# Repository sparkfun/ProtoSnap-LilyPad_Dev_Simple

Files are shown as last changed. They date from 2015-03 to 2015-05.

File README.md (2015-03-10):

SparkFun ProtoSnap - LilyPad Development Simple
================================================

SparkFun ProtoSnap - LilyPad Development Simple

[*SparkFun ProtoSnap - LilyPad Development Simple (DEV-11201)*](https://www.sparkfun.com/products/11201)

The ProtoSnap LilyPad Simple Development board is a great way to get started in programmable e-textiles. 
By combining a LilyPad Simple board with 4 LED boards and a buzzer, the ProtoSnap LilyPad Simple Development board gives you everything you need to learn the basics. 

Repository Contents
-------------------

* **/Hardware** - All Eagle design files (.brd, .sch)

License Information
-------------------
The hardware is released under [Creative Commons ShareAlike 4.0 International](https://creativecommons.org/licenses/by-sa/4.0/).

Distributed as-is; no warranty is given.

_**Note:** A portion of this sale is given back to Dr. Leah Buechley for continued development and education of e-textiles and also to Arduino LLC to help fund continued development of new tools and new IDE features._

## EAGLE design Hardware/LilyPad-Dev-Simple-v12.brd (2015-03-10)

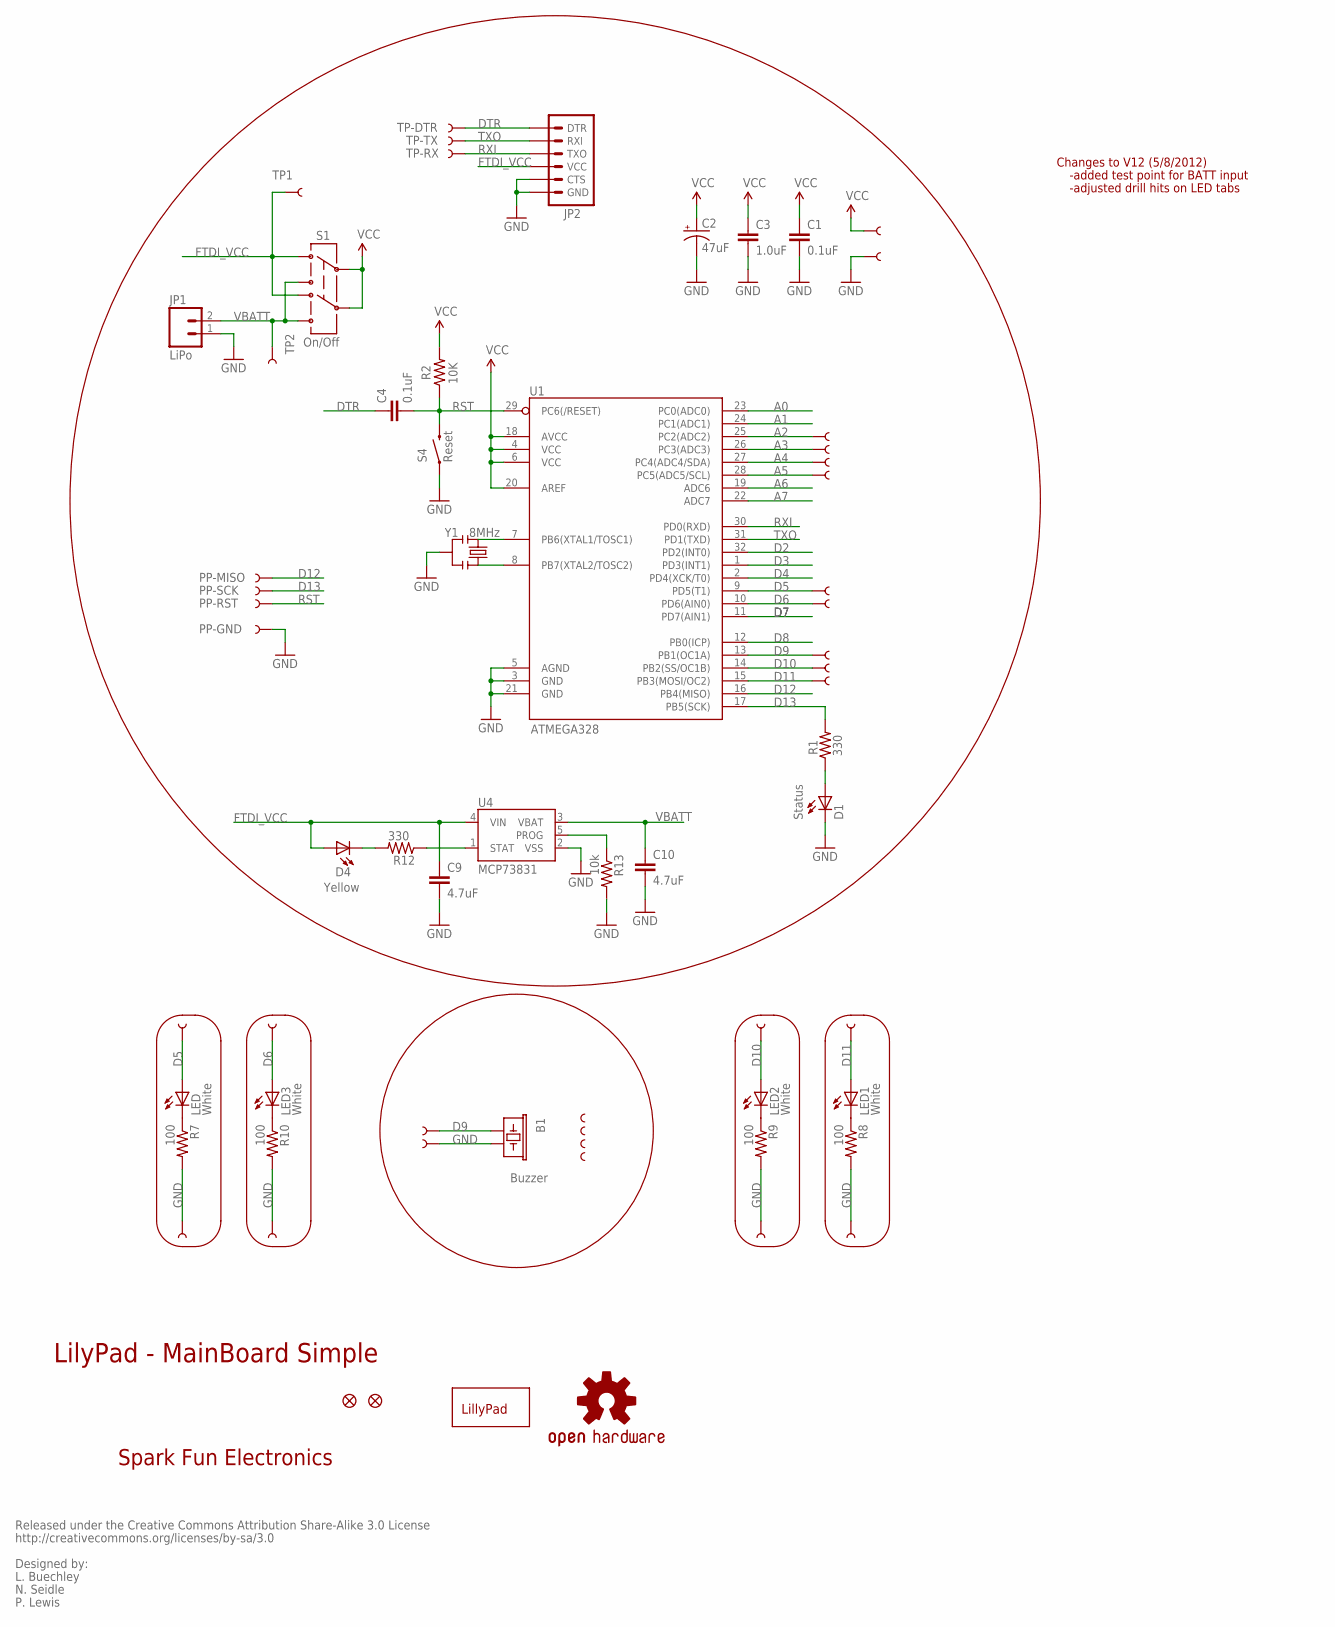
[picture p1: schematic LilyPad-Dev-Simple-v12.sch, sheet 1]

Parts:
1, 2, 3, 4: SEWTAP-NOHOLE2; PETAL-NOHOLE-2SIDE
A2/16, A3/17, A4/18, A5/19: SEWTAP9; PETAL-LONG-1-2SIDE
B1: Buzzer; BUZZER-CCV
C1, C4: 0.1uF; 0402-CAP
C2: 47uF; EIA3528
C3: 1.0uF; 0402-CAP
C9, C10: 4.7uF; 0402-CAP
D1: Status; LED-0603
D4: Yellow; LED-0603
JP1: LiPo; JST-2-SMD
JP2: ARDUINO_SERIAL_PROGRAMSMD; 1X06-SMD
JP3, JP4: FIDUCIAL1X2; FIDUCIAL-1X2
LED, LED1, LED2, LED3: White; LED-1206
LED+, LED+1, LED+2, LED+3: SEWTAP6; PETAL-SMALL-2SIDE
LED-, LED-1, LED-2, LED-3: SEWTAP6; PETAL-SMALL-2SIDE
LOGO: LOGO-LPLPA; LOGO-LPA
PP-GND: TEST-POINT3X5; PAD.03X.05
PP-MISO: TEST-POINT3X5; PAD.03X.05
PP-RST: TEST-POINT3X5; PAD.03X.05
PP-SCK: TEST-POINT3X5; PAD.03X.05
R1, R12: 330; 0402-RES
R2: 10K; 0402-RES
R7, R8, R9, R10: 100; 0603-RES
R13: 10k; 0402-RES
S1: On/Off; AYZ0202
S4: Reset; TACTILE_SWITCH_SMD
TP1, TP2: TEST-POINT3X5; PAD.03X.05
TP-DTR: TEST-POINT3X5; PAD.03X.05
TP-RX: TEST-POINT3X5; PAD.03X.05
TP-TX: TEST-POINT3X5; PAD.03X.05
U1: ATMEGA328; TQFP32-08
U4: MCP73831; SOT23-5
U$1, U$4, U$37, U$39, U$41, U$43, U$45: SEWTAP9; PETAL-LONG-1-2SIDE
U$2: OSHW-LOGOS; OSHW-LOGO-S
U$32-, U$33+: SEWTAP6; PETAL-SMALL
Y1: 8MHz; RESONATOR-SMD

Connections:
A0: U1.23 (PC0(ADC0))
A1: U1.24 (PC1(ADC1))
A2: A2/16.1, U1.25 (PC2(ADC2))
A3: A3/17.1, U1.26 (PC3(ADC3))
A4: A4/18.1, U1.27 (PC4(ADC4/SDA))
A5: A5/19.1, U1.28 (PC5(ADC5/SCL))
A6: U1.19 (ADC6)
A7: U1.22 (ADC7)
D2: U1.32 (PD2(INT0))
D3: U1.1 (PD3(INT1))
D4: U1.2 (PD4(XCK/T0))
D5: LED.A, LED+.1, U1.9 (PD5(T1)), U$41.1
D6: LED3.A, LED+3.1, U1.10 (PD6(AIN0)), U$1.1
D7: U1.11 (PD7(AIN1))
D8: U1.12 (PB0(ICP))
D9: B1.+ (1), U1.13 (PB1(OC1A)), U$33+.1, U$37.1
D10: LED2.A, LED+2.1, U1.14 (PB2(SS/OC1B)), U$39.1
D11: LED1.A, LED+1.1, U1.15 (PB3(MOSI/OC2)), U$4.1
D12: PP-MISO.P$1, U1.16 (PB4(MISO))
D13: PP-SCK.P$1, R1.2, U1.17 (PB5(SCK))
DTR: C4.1, JP2.1 (DTR), TP-DTR.P$1
FTDI_VCC: C9.1, D4.A, JP2.4 (VCC), S1.3 (1), S1.6 (4), TP1.P$1, U4.4 (VIN)
GND: B1.- (2), C1.2, C2.C (-), C3.2, C9.2, C10.2, D1.C, JP1.1, JP2.5 (CTS), JP2.6 (GND), LED-.1, LED-1.1, LED-2.1, LED-3.1, PP-GND.P$1, R7.2, R8.2, R9.2, R10.2, R13.2, S4.1, U1.3 (GND), U1.5 (AGND), U1.21 (GND), U4.2 (VSS), U$32-.1, U$43.1, Y1.2
unnamed: U1.7 (PB6(XTAL1/TOSC1)), Y1.1
unnamed: D1.A, R1.1
unnamed: U1.8 (PB7(XTAL2/TOSC2)), Y1.3
unnamed: LED.C, R7.1
unnamed: LED1.C, R8.1
unnamed: LED2.C, R9.1
unnamed: LED3.C, R10.1
unnamed: D4.C, R12.2
PROG: R13.1, U4.5 (PROG)
RST: C4.2, PP-RST.P$1, R2.1, S4.3 (2), U1.29 (PC6(/RESET))
RXI: JP2.3 (TXO), TP-RX.P$1, U1.30 (PD0(RXD))
STAT: R12.1, U4.1 (STAT)
TXO: JP2.2 (RXI), TP-TX.P$1, U1.31 (PD1(TXD))
VBATT: C10.1, JP1.2, S1.1 (3), S1.4 (6), TP2.P$1, U4.3 (VBAT)
VCC: C1.1, C2.A (+), C3.1, R2.2, S1.2, S1.5, U1.4 (VCC), U1.6 (VCC), U1.18 (AVCC), U1.20 (AREF), U$45.1

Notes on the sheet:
LilyPad - MainBoard Simple
Spark Fun Electronics
Released under the Creative Commons Attribution Share-Alike 3.0 License
http://creativecommons.org/licenses/by-sa/3.0
Designed by:
L. Buechley
N. Seidle
P. Lewis
Changes to V12 (5/8/2012)
-added test point for BATT input
-adjusted drill hits on LED tabs

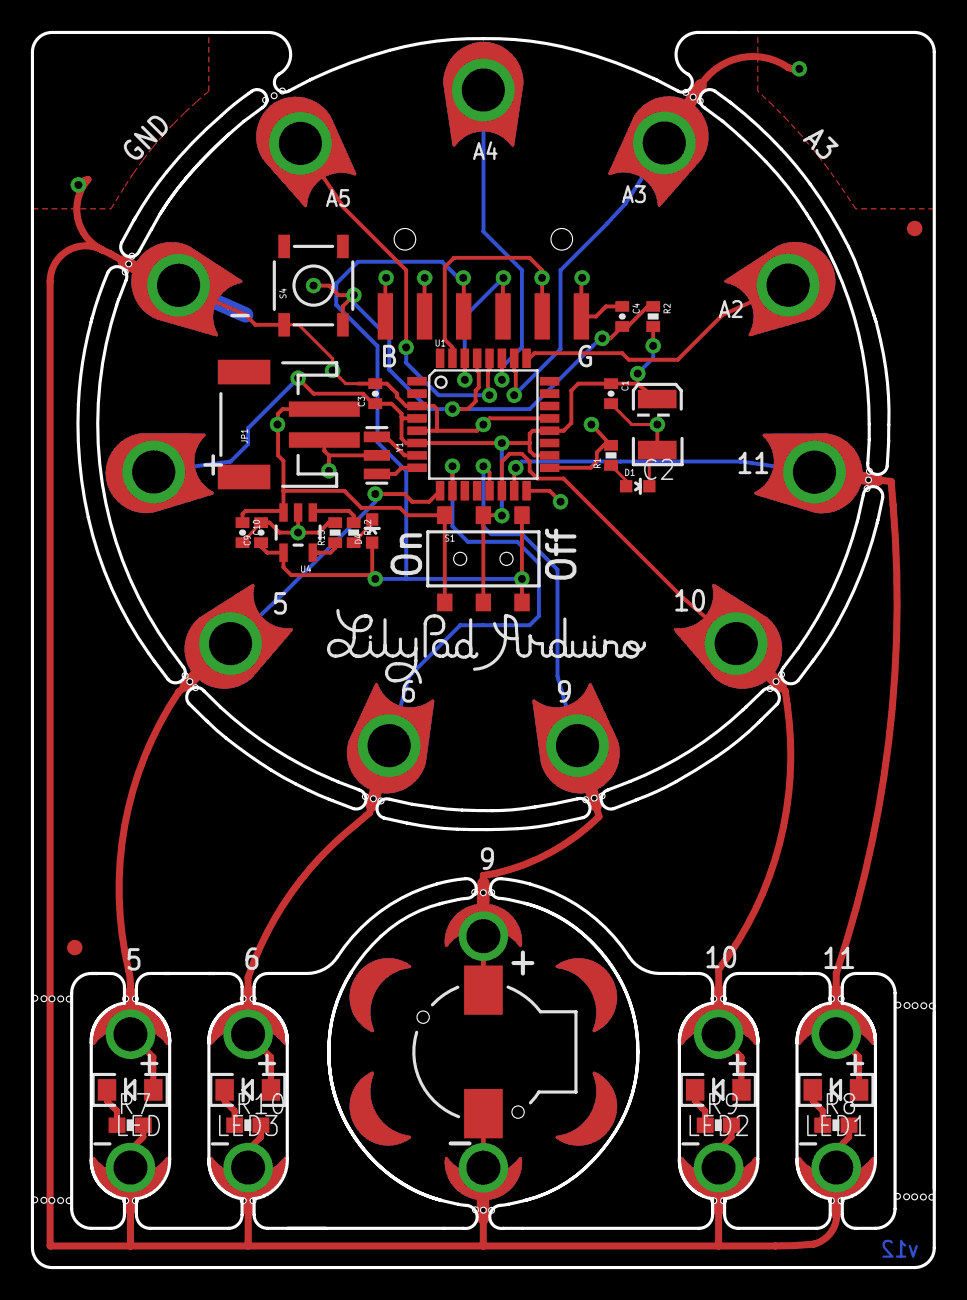
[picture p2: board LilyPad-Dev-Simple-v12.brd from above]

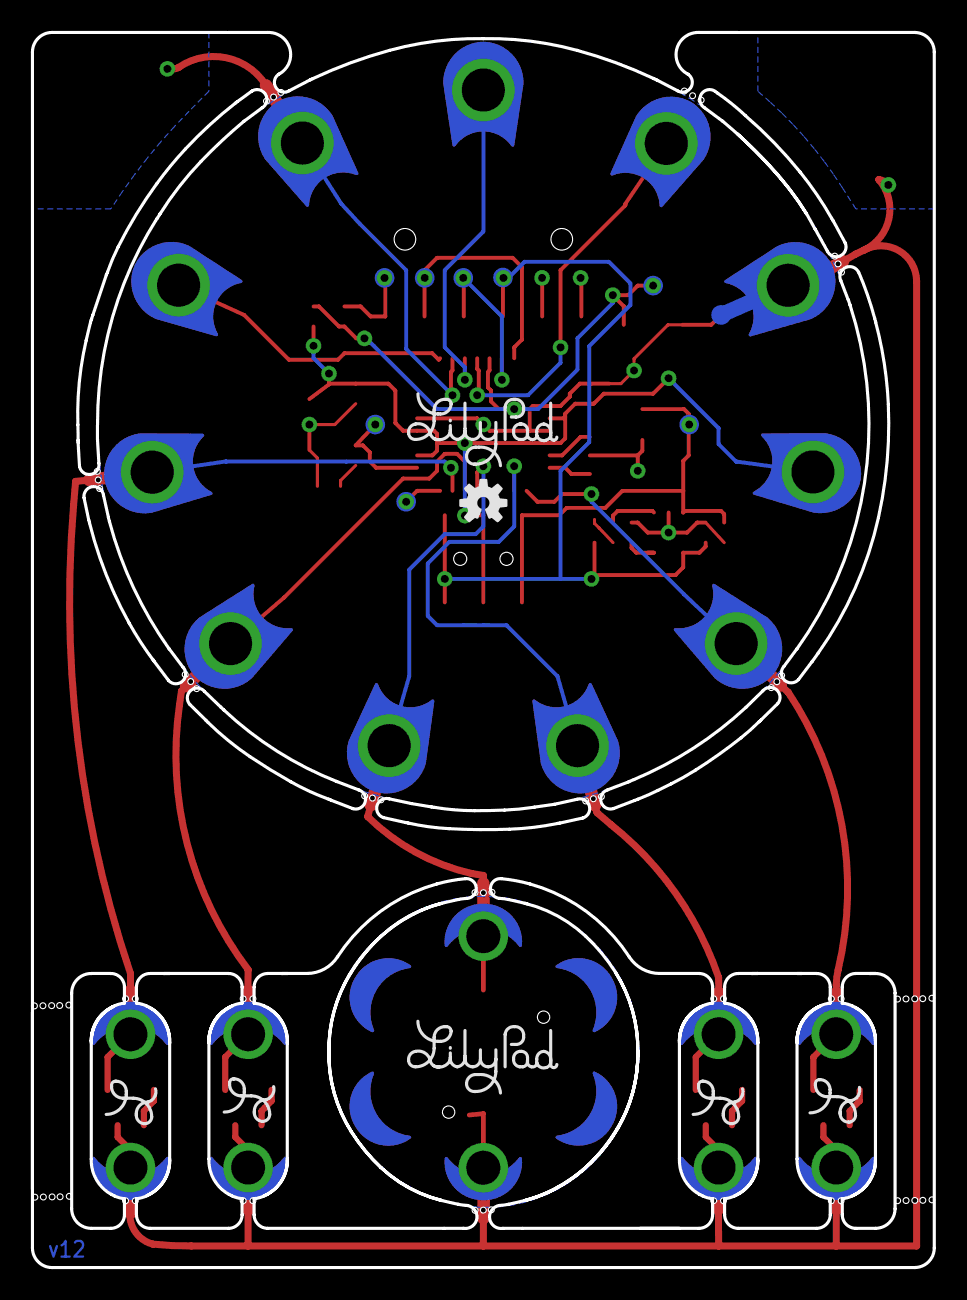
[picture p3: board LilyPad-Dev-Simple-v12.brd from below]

Board: 2 copper layers, 58.4 x 80.0 mm, 73 parts (16 on the bottom side), 29 nets.

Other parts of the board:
LOGO3, LOGO4, LOGO5, LOGO6: LOGO-LPL; LOGO-L
U$21, U$35: LOGO-LPLP; LOGO-LILYPAD
U$36: LILYPAD-BRD-LAYERS-SMALL

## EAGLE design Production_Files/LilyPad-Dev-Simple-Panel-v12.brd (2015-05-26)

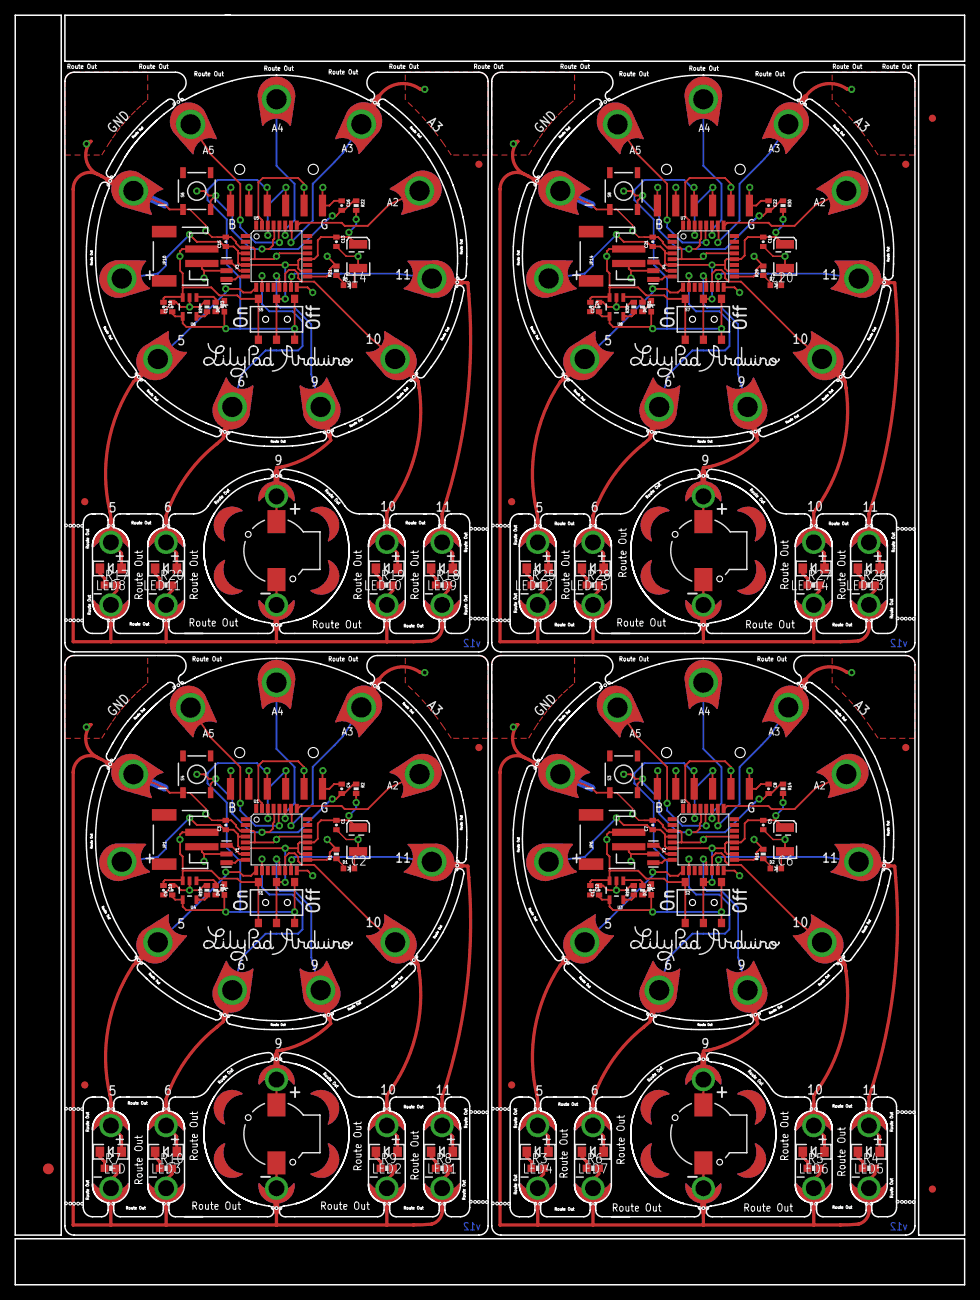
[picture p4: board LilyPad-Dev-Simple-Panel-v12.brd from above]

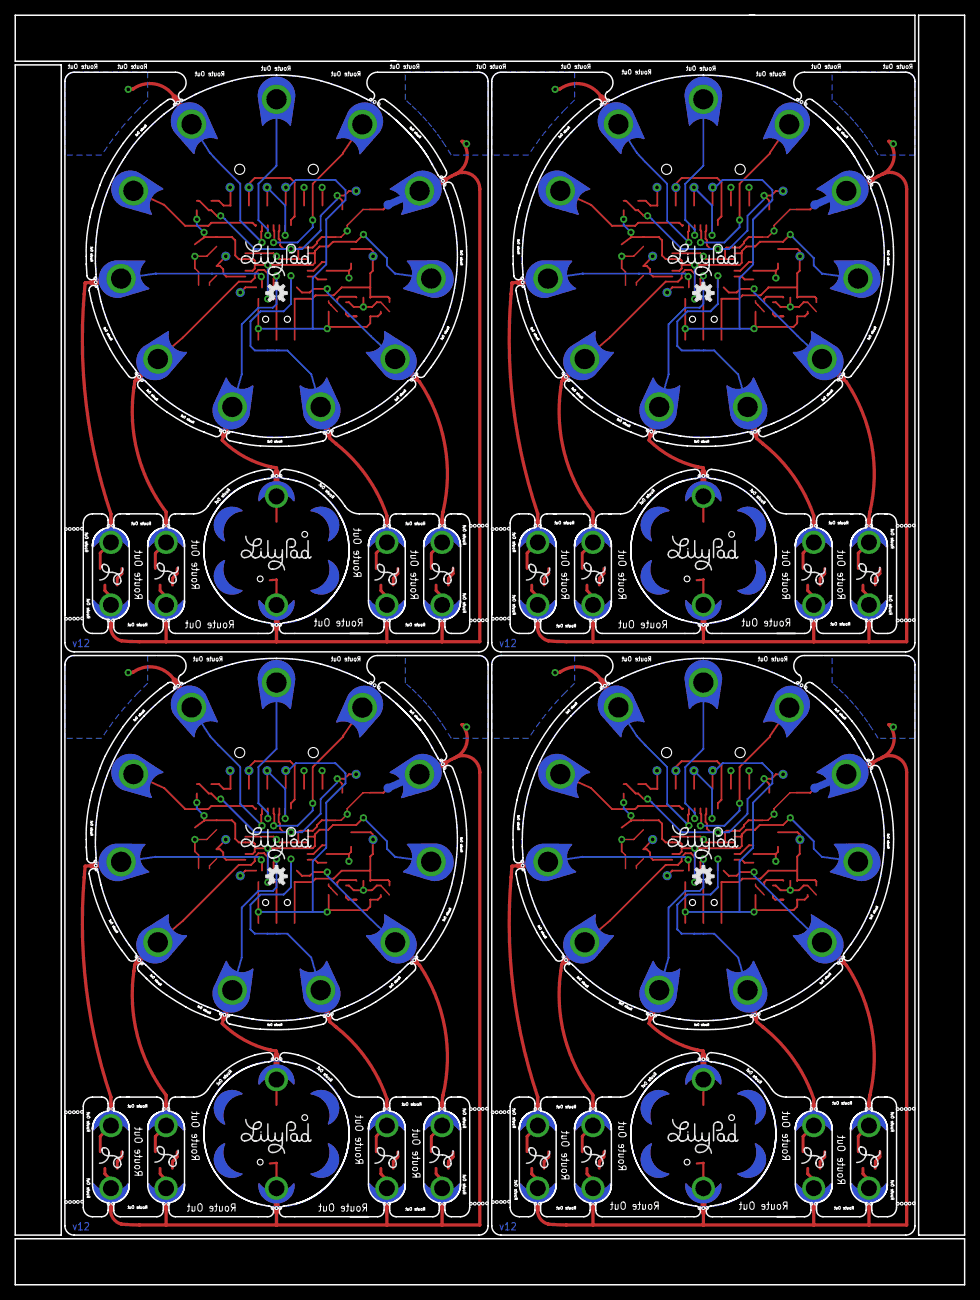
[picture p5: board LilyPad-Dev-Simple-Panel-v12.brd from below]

Board: 2 copper layers, 131.1 x 175.3 mm, 295 parts (64 on the bottom side), 116 nets.

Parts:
1, 2, 3, 4, 5, 6, 7, 8, 9, 10, 11, 12, 13, 14, 15, 16: SEWTAP-NOHOLE2; PETAL-NOHOLE-2SIDE
A2/1, A2/2, A2/3, A2/16, A3/1, A3/2, A3/3, A3/17, A4/1, A4/2, A4/3, A4/18, A5/1, A5/2, A5/3, A5/19: SEWTAP9; PETAL-LONG-1-2SIDE
B1, B2, B3, B4: Buzzer; BUZZER-CCV
C1, C4, C5, C8, C13, C16, C19, C22: 0.1uF; 0402-CAP
C2, C6, C14, C20: 47uF; EIA3528
C3, C7, C15, C21: 1.0uF; 0402-CAP
C9, C10, C11, C12, C17, C18, C23, C24: 4.7uF; 0402-CAP
D1, D2, D5, D7: Status; LED-0603
D3, D4, D6, D8: Yellow; LED-0603
E$1: FIDUCIAL-1.5X3
E$4, E$5: FIDUCIAL-1X2
JP1, JP6, JP10, JP14: LiPo; JST-2-SMD
JP2, JP5, JP9, JP13: 1X06-SMD
JP3, JP4, JP7, JP8, JP11, JP12, JP15, JP16: FIDUCIAL1X2; FIDUCIAL-1X2
LED, LED1, LED2, LED3, LED4, LED5, LED6, LED7, LED8, LED9, LED10, LED11, LED12, LED13, LED14, LED15: White; LED-1206
LED+, LED+1, LED+2, LED+3, LED+4, LED+5, LED+6, LED+7, LED+8, LED+9, LED+10, LED+11, LED+12, LED+13, LED+14, LED+15: SEWTAP6; PETAL-SMALL-2SIDE
LED-, LED-1, LED-2, LED-3, LED-4, LED-5, LED-6, LED-7, LED-8, LED-9, LED-10, LED-11, LED-12, LED-13, LED-14, LED-15: SEWTAP6; PETAL-SMALL-2SIDE
LOGO, LOGO9, LOGO14, LOGO19: LOGO-LPLPA; LOGO-LPA
LOGO1, LOGO2, LOGO3, LOGO4, LOGO5, LOGO6, LOGO7, LOGO8, LOGO10, LOGO11, LOGO12, LOGO13, LOGO15, LOGO16, LOGO17, LOGO18: LOGO-LPL; LOGO-L
PP-GND, PP-GND1, PP-GND2, PP-GND3: PAD.03X.05
PP-MISO, PP-MISO1, PP-MISO2, PP-MISO3: PAD.03X.05
PP-RST, PP-RST1, PP-RST2, PP-RST3: PAD.03X.05
PP-SCK, PP-SCK1, PP-SCK2, PP-SCK3: PAD.03X.05
R1, R11, R12, R15, R21, R23, R29, R31: 330; 0402-RES
R2, R14, R22, R30: 10K; 0402-RES
R3, R4, R5, R6, R7, R8, R9, R10, R17, R18, R19, R20, R25, R26, R27, R28: 100; 0603-RES
R13, R16, R24, R32: 10k; 0402-RES
S1, S2, S5, S7: On/Off; AYZ0202
S3, S4, S6, S8: Reset; TACTILE_SWITCH_SMD
TP1, TP2, TP3, TP4, TP5, TP6, TP7, TP8: PAD.03X.05
TP-DTR, TP-DTR1, TP-DTR2, TP-DTR3: PAD.03X.05
TP-RX, TP-RX1, TP-RX2, TP-RX3: PAD.03X.05
TP-TX, TP-TX1, TP-TX2, TP-TX3: PAD.03X.05
U1, U2, U5, U7: ATMEGA328; TQFP32-08
U3, U4, U6, U8: MCP73831; SOT23-5
U$1, U$4, U$5, U$6, U$7, U$8, U$9, U$10, U$11, U$16, U$17, U$18, U$19, U$20, U$22, U$23, U$28, U$29, U$30, U$31, U$32, U$33, U$34, U$37, U$39, U$41, U$43, U$45: SEWTAP9; PETAL-LONG-1-2SIDE
U$2, U$14, U$26, U$42: OSHW-LOGOS; OSHW-LOGO-S
U$3, U$12, U$15, U$21, U$24, U$27, U$35, U$38: LOGO-LPLP; LOGO-LILYPAD
U$13, U$25, U$36, U$40: LILYPAD-BRD-LAYERS-SMALL
U$32-, U$32-1, U$32-2, U$32-3, U$33+, U$33+1, U$33+2, U$33+3: SEWTAP6; PETAL-SMALL-2SIDE
Y1, Y2, Y3, Y4: 8MHz; RESONATOR-SMD

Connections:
A2: A2/16.1, U1.25
A3: A3/17.1, U1.26
A4: A4/18.1, U1.27
A5: A5/19.1, U1.28
A8: A2/1.1, U2.25
A9: A3/1.1, U2.26
A10: A4/1.1, U2.27
A11: A5/1.1, U2.28
A16: A2/2.1, U5.25
A17: A3/2.1, U5.26
A18: A4/2.1, U5.27
A19: A5/2.1, U5.28
A24: A2/3.1, U7.25
A25: A3/3.1, U7.26
A26: A4/3.1, U7.27
A27: A5/3.1, U7.28
D1: LED5.A, LED+5.1, U2.15, U$11.1
D5: LED.A, LED+.1, U1.9, U$41.1
D6: LED3.A, LED+3.1, U1.10, U$1.1
D9: B1.+, U1.13, U$33+.1, U$37.1
D10: LED2.A, LED+2.1, U1.14, U$39.1
D11: LED1.A, LED+1.1, U1.15, U$4.1
D12: PP-MISO.P$1, U1.16
D13: PP-SCK.P$1, R1.2, U1.17
D14: PP-SCK1.P$1, R11.2, U2.17
D15: LED4.A, LED+4.1, U2.9, U$8.1
D16: B2.+, U2.13, U$6.1, U$33+1.1
D17: LED7.A, LED+7.1, U2.10, U$5.1
D18: LED6.A, LED+6.1, U2.14, U$7.1
D24: PP-MISO1.P$1, U2.16
D25: LED9.A, LED+9.1, U5.15, U$23.1
D26: PP-SCK2.P$1, R21.2, U5.17
D27: LED8.A, LED+8.1, U5.9, U$19.1
D28: B3.+, U5.13, U$17.1, U$33+2.1
D29: LED11.A, LED+11.1, U5.10, U$16.1
D30: LED10.A, LED+10.1, U5.14, U$18.1
D36: PP-MISO2.P$1, U5.16
D37: LED13.A, LED+13.1, U7.15, U$34.1
D38: PP-SCK3.P$1, R29.2, U7.17
D39: LED12.A, LED+12.1, U7.9, U$31.1
D40: B4.+, U7.13, U$29.1, U$33+3.1
D41: LED15.A, LED+15.1, U7.10, U$28.1
D42: LED14.A, LED+14.1, U7.14, U$30.1
D48: PP-MISO3.P$1, U7.16
DTR: C4.1, JP2.1, TP-DTR.P$1
DTR1: C8.1, JP5.1, TP-DTR1.P$1
DTR2: C16.1, JP9.1, TP-DTR2.P$1
DTR3: C22.1, JP13.1, TP-DTR3.P$1
FTDI_VCC: C9.1, D4.A, JP2.4, S1.3, S1.6, TP1.P$1, U4.4
FTDI_VCC1: C11.1, D3.A, JP5.4, S2.3, S2.6, TP3.P$1, U3.4
FTDI_VCC2: C17.1, D6.A, JP9.4, S5.3, S5.6, TP5.P$1, U6.4
FTDI_VCC3: C23.1, D8.A, JP13.4, S7.3, S7.6, TP7.P$1, U8.4
GND: B1.-, C1.2, C2.C, C3.2, C9.2, C10.2, D1.C, JP1.1, JP2.5, JP2.6, LED-.1, LED-1.1, LED-2.1, LED-3.1, PP-GND.P$1, R7.2, R8.2, R9.2, R10.2, R13.2, S4.1, U1.3, U1.5, U1.21, U4.2, U$32-.1, U$43.1, Y1.2
GND1: B2.-, C5.2, C6.C, C7.2, C11.2, C12.2, D2.C, JP5.5, JP5.6, JP6.1, LED-4.1, LED-5.1, LED-6.1, LED-7.1, PP-GND1.P$1, R3.2, R4.2, R5.2, R6.2, R16.2, S3.1, U2.3, U2.5, U2.21, U3.2, U$9.1, U$32-1.1, Y2.2
GND2: B3.-, C13.2, C14.C, C15.2, C17.2, C18.2, D5.C, JP9.5, JP9.6, JP10.1, LED-8.1, LED-9.1, LED-10.1, LED-11.1, PP-GND2.P$1, R17.2, R18.2, R19.2, R20.2, R24.2, S6.1, U5.3, U5.5, U5.21, U6.2, U$20.1, U$32-2.1, Y3.2
GND3: B4.-, C19.2, C20.C, C21.2, C23.2, C24.2, D7.C, JP13.5, JP13.6, JP14.1, LED-12.1, LED-13.1, LED-14.1, LED-15.1, PP-GND3.P$1, R25.2, R26.2, R27.2, R28.2, R32.2, S8.1, U7.3, U7.5, U7.21, U8.2, U$32.1, U$32-3.1, Y4.2
unnamed: U1.7, Y1.1
unnamed: D1.A, R1.1
unnamed: U1.8, Y1.3
unnamed: LED4.C, R3.1
unnamed: LED5.C, R4.1
unnamed: LED6.C, R5.1
unnamed: LED7.C, R6.1
unnamed: D2.A, R11.1
unnamed: U2.7, Y2.1
unnamed: U2.8, Y2.3
unnamed: D3.C, R15.2
unnamed: LED8.C, R17.1
unnamed: LED9.C, R18.1
unnamed: LED10.C, R19.1
unnamed: LED11.C, R20.1
unnamed: LED.C, R7.1
unnamed: D5.A, R21.1
unnamed: U5.7, Y3.1
unnamed: LED1.C, R8.1
unnamed: U5.8, Y3.3
unnamed: D6.C, R23.2
unnamed: LED2.C, R9.1
unnamed: LED12.C, R25.1
unnamed: LED3.C, R10.1
unnamed: LED13.C, R26.1
unnamed: LED14.C, R27.1
unnamed: LED15.C, R28.1
unnamed: D7.A, R29.1
unnamed: U7.7, Y4.1
unnamed: D4.C, R12.2
unnamed: U7.8, Y4.3
unnamed: D8.C, R31.2
PROG: R13.1, U4.5
PROG1: R16.1, U3.5
PROG2: R24.1, U6.5
PROG3: R32.1, U8.5
RST: C4.2, PP-RST.P$1, R2.1, S4.3, U1.29
RST1: C8.2, PP-RST1.P$1, R14.1, S3.3, U2.29
RST2: C16.2, PP-RST2.P$1, R22.1, S6.3, U5.29
RST3: C22.2, PP-RST3.P$1, R30.1, S8.3, U7.29
RXI: JP2.3, TP-RX.P$1, U1.30
RXI1: JP5.3, TP-RX1.P$1, U2.30
RXI2: JP9.3, TP-RX2.P$1, U5.30
RXI3: JP13.3, TP-RX3.P$1, U7.30
STAT: R12.1, U4.1
STAT1: R15.1, U3.1
STAT2: R23.1, U6.1
STAT3: R31.1, U8.1
TXO: JP2.2, TP-TX.P$1, U1.31
TXO1: JP5.2, TP-TX1.P$1, U2.31
TXO2: JP9.2, TP-TX2.P$1, U5.31
TXO3: JP13.2, TP-TX3.P$1, U7.31
VBATT: C10.1, JP1.2, S1.1, S1.4, TP2.P$1, U4.3
VBATT1: C12.1, JP6.2, S2.1, S2.4, TP4.P$1, U3.3
VBATT2: C18.1, JP10.2, S5.1, S5.4, TP6.P$1, U6.3
VBATT3: C24.1, JP14.2, S7.1, S7.4, TP8.P$1, U8.3
VCC: C1.1, C2.A, C3.1, R2.2, S1.2, S1.5, U1.4, U1.6, U1.18, U1.20, U$45.1
VCC1: C5.1, C6.A, C7.1, R14.2, S2.2, S2.5, U2.4, U2.6, U2.18, U2.20, U$10.1
VCC2: C13.1, C14.A, C15.1, R22.2, S5.2, S5.5, U5.4, U5.6, U5.18, U5.20, U$22.1
VCC3: C19.1, C20.A, C21.1, R30.2, S7.2, S7.5, U7.4, U7.6, U7.18, U7.20, U$33.1

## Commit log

2015-03-10 Adding hardware files, updating README
    [LilyPad-Dev-Simple-v12.brd, LilyPad-Dev-Simple-v12.sch]
2015-05-26 created panel v12
    [LilyPad-Dev-Simple-Panel-v12.brd]

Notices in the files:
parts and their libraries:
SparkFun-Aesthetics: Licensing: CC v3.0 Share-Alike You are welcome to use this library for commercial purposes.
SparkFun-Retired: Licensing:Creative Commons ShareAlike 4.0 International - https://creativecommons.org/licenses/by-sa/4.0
